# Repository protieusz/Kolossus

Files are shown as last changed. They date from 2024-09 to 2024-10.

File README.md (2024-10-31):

# Kolossus
Kolossus, a unisplit angled Katana layout with a 25mm trackball and a Panasonic roller encoder remixed from clops pcb designed by [calvin-mcd](https://github.com/calvin-mcd/clops). KLE by noelle (deer) and HA HA HA.

# PCBWay Sponsorship
The Kolossus PCB was sponsored by PCBWay. Thank you PCBWay! For all your PCB prototype prints and PCBA needs you can count on PCBWay. Easy and worry free service. You submit your gerber, BOM and placement files via their website. Enter the PCB dimensions and the quantity of the prints and select the recommend shipping service, for me it is the DHL Express (DTP) for hassle free delivery.  All customs paid for. PCBWay will email you component placement clear detailed pictures for validation before soldering the rest of the PCBs.

# Description
Kolossus "...is a qazlike unibody split sub40s keyboard. The KLE and firmware is by ha ha ha which itself is inspired by a KLE from Noelle. PCB is designed by Calvin0563." Copied from Calvin's GitHub linked above. 
Kolossus is a heavy remix of clops by adding a full case to the PCB that was made from scratch using EasyEDA by extracting vital files from the Calvin0563's clops PCB files. Initially the name was Colossus but changed to Kolossus via HA HA HA's suggestion to give it a more stylist name.
Here are the list of modifications:

-Center encoder is now a 25mm trackball powered by PMW3360 sensor.

-Full enclosure case with 4 RGB cut outs.

-5mm integrated switch plate to the top case.

-Use M2 brass hot inserts 3.2mm diameter and 4mm length for the M2 screws to secure the case. I forgot how long is my M2 screws are but they should be greater than 10mm so estimated around 14.6mm. Play around with and buy multiple M2 lenght screws.

-PCB is powered by [RP2040 Zero Super Mini](https://www.aliexpress.com/item/1005007292787135.html?spm=a2g0o.order_list.order_list_main.11.46301802CibF9u) where the bottom of the mcu is flush and can sit on top of the Excelsior PCB with no issues.

-For diodes, I decided to try out the BAV70 so that I solder less diodes. I would only need to solder on 17 diodes instead of 34

-QMK code is borrowed from aki27 bally and modified the matrix to fit my Kolossus. No suppport will be given since I just copy and paste.

-Below the trackball is the optional Panasonic EVQ roller encoder or a MX switch. Case cut out was done to acoomodate the Panasonic encoder.

-Stabilizers cutout was made but was not sure about the dimensions since I have never used stabs before so a STEP case file will be included so you can cut the stab cut out further if needed. I am planning to build mine without any stabs. As always print at your own risk. No support will be given.

-Case usb c opening ~~will be~~ adjusted ~~in the future~~ to accommodate the wider USB C magnetic port. Updated bottom case on October 31, 2024.

-New full case variant designs will be printed soon. Stay tuned.

-Full production build on Oct 22, 2024.

-For Encoder soldering, the MCU will need to be soldered a little bit to the left so that there is a little bit more space for the tiny GPIO pads to be exposed for surgical soldering. The pads are tiny so I suggest a ribbon cable type cables to be use. I have not solder build the pcb with roller encoder yet. I am currently still waiting for 2x RP2040 Super mini mcus to arrive from Aliexpress.

# Disclaimer (Also copied from Calvin0563's GitHub page)

Please note that this project is a work in progress with no guarantees of a working outcome. No-one involved in this project is responsible for any usage issues that may arise. However, feel free to edit, modify and otherwise utilise these files.

# Full Production Build
Zaku 2.0 case Oct 30, 2024











Zaku Case Oct 25, 2024


































# Render
Screenshot 2024-09-26 at 8 04 03 AM
Screenshot 2024-09-26 at 8 04 16 AM
Screenshot 2024-09-26 at 8 04 31 AM
Screenshot 2024-09-26 at 8 04 43 AM
Screenshot 2024-09-20 at 4 23 53 PM
Screenshot 2024-09-20 at 4 23 34 PM
Screenshot 2024-09-20 at 4 19 32 PM
Screenshot 2024-09-20 at 4 18 53 PM
Screenshot 2024-09-20 at 4 24 03 PM
Screenshot 2024-09-20 at 10 55 51 AM
Screenshot 2024-09-20 at 10 55 34 AM
Screenshot 2024-09-20 at 10 55 24 AM
Screenshot 2024-09-20 at 1 13 23 PM
Screenshot 2024-09-20 at 1 34 12 AM
Screenshot 2024-09-19 at 9 18 57 PM
Screenshot 2024-09-19 at 9 19 31 PM

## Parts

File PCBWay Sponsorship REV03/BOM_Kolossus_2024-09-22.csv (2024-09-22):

ID | Name | Designator | Footprint | Quantity | Manufacturer Part | Manufacturer | Supplier | Supplier Part | Price | link
1 | NO | ENCA,ENCB | PIN 1-PIN | 2
2 | Switch | K000,K001,K002,K003,K004,K006,K007,K008,K009,K010,K100,K101,K102,K103,K104,K106,K107,K108,K109,K110,K200,K201,K202,K203,K204,K206,K207,K208,K209,K210,K303,K305,K307 | CHERRY_MX_100_MILLMAX | 33
3 | MX_ALPS-2U-REVERSEDSTABILIZERS-NOLED | KK306,KK304 | MX_ALPS-2U-REVERSEDSTABILIZERS-NOLED | 2
4 | Roll Encoder - EVQWGD001 | EC305 | EVQWGD001 ENCODER | 1 | EVQWGD001 | Panasonic | Aliexpress | EVQWGD001
5 | BAV70-C68978 | D007,D107,D207,D209,D306,D305,D000,D002,D004,D008,D100,D102,D104,D108,D200,D202,D204,D303 | SOT-23-3_L3.0-W1.7-P0.95-LS2.9-BR | 18 | BAV70 | CJ(江苏长电/长晶) | LCSC | C68978 | 0.019 | https://item.szlcsc.com/139341.html
6 | 4.7uF | C17,C19,C20 | C0402 | 3 | CL05A475MP5NRNC | SAMSUNG(三星) | LCSC | C23733 | 0.005 | https://lcsc.com/eda_search?q=C23733&%26type=1&ref=editor
7 | 100nF | C18 | C0402 | 1 | CL05B104KB54PNC | SAMSUNG(三星) | LCSC | C307331 | 0.005 | https://lcsc.com/eda_search?q=C307331&%26type=1&ref=editor
8 | 10kΩ | R10,R12,R13 | R0402 | 3 | 0402WGF1002TCE | UNI-ROYAL(厚声) | LCSC | C25744 | 0.001 | https://lcsc.com/eda_search?q=C25744&%26type=1&ref=editor
9 | 39Ω | R11 | R0402 | 1 | 0402WGJ0390TCE | UNI-ROYAL(厚声) | LCSC | C25164 |  | https://lcsc.com/eda_search?q=C25164&%26type=1&ref=editor
10 | 15kΩ | R14 | R0402 | 1 | 0402WGF1502TCE | UNI-ROYAL(厚声) | LCSC | C25756 | 0.001 | https://lcsc.com/eda_search?q=C25756&%26type=1&ref=editor
11 | AP2127K-ADJTRG1 | U10 | SOT-23-5_L3.0-W1.7-P0.95-LS2.8-BR | 1 | AP2127K-ADJTRG1 | DIODES(美台) | LCSC | C96343 | 0.074 | https://lcsc.com/eda_search?q=C96343&%26type=1&ref=editor
12 | PMW3360DM-T2QU | U11 | PMW3360DM-T2QU.PACK | 1 | PMW3360DM-T2QU |  |  |  |  | http://www.pixart.com/upload/PMS0058-PMW3360DM-T2QU-NNDS-R1.30-06042016_20160902201411.pdf
13 | RP2040-TINY | U2 | COMM-SMD_23P-P2.54-L23.5-W18.0_RP2040-TINY | 1 | RP2040-Tiny | Waveshare(微雪电子) | LCSC | C7437606 | 5.586 | https://atta.szlcsc.com/upload/public/pdf/source/20230712/B68EE20814230DC1A1AC8A477766A0F3.pdf
14 | SN74LVC1T45DCKR | U6L | SC-70-6_L2.2-W1.3-P0.65-LS2.2-BR | 1 | SN74LVC1T45DCKR | TI(德州仪器) | LCSC | C9382 | 0.118 | https://item.szlcsc.com/51804.html
15 | SK6812MINI-E_C5149201 | U20,U21,U22,U23 | LED-SMD_L3.2-W2.8-TR | 4 | SK6812MINI-E | 欧思科光电 | LCSC | C5149201 | 0.092 | https://lcsc.com/eda_search?q=C5149201&%26type=1&ref=editor

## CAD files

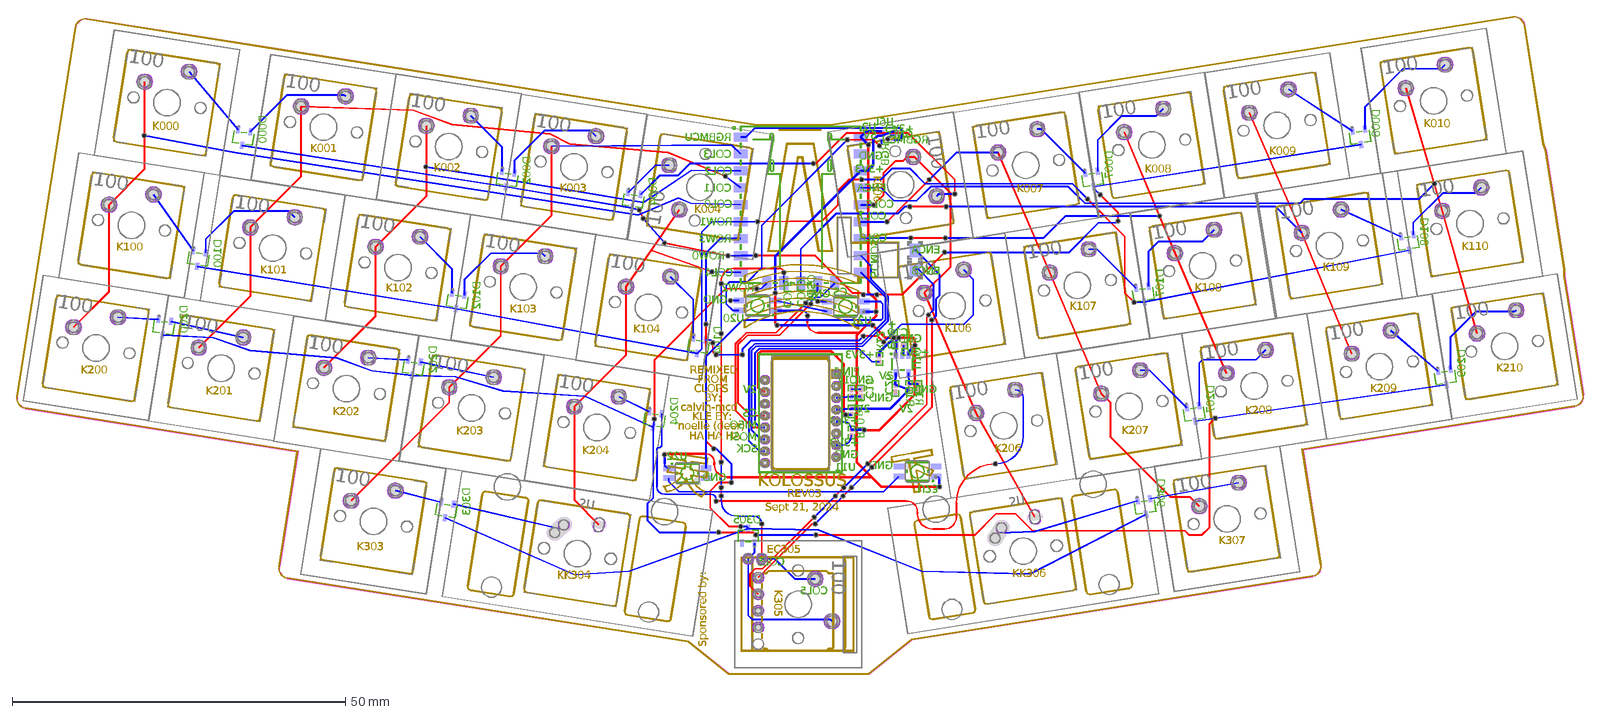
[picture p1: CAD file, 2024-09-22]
Final PCB Reference Corrected Sensor/PCB_Kolossus-Corrected-Sensor_2024-09-22.dxf
KOLOSSUS
REV03
Sept 21, 2024
REMIXED
FROM
CLOPS
BY:
calvin-mcd
KLE BY:
noelle (deer)
HA HA HA
Sponsored by:
PIN 1
GND
2V
+3V3
CS
MISO
MOSI
SCK
COL5
5V
RGBMCU
RGB
ENCA
COL6
COL7
COL8
COL9
COL4
ROW0
ROW3
ROW1
COL0
COL1
COL2
COL3
ROW2
K305
100
KK306
2U
KK304
K006
K007
K008
K009
K010
K106
K107
K108
K109
K110
K206
K207
K208
K209
K210
K307
EC305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

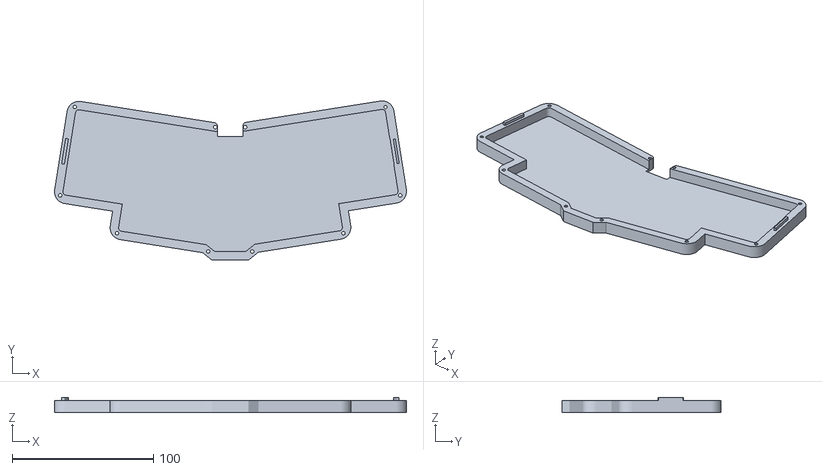
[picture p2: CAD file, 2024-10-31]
STLs/Kolossus Bottom WiderUSB.stl
249.1 x 112.6 x 10.6

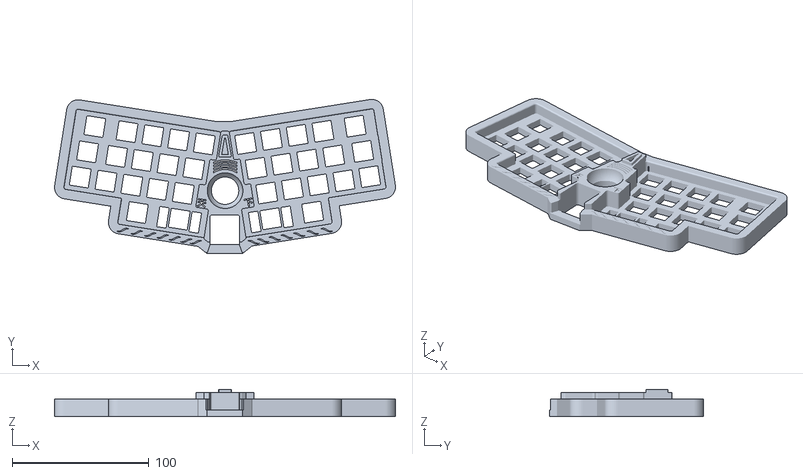
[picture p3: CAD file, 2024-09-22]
STLs/Kolossu Top Case.stl
249.1 x 112.6 x 20.0

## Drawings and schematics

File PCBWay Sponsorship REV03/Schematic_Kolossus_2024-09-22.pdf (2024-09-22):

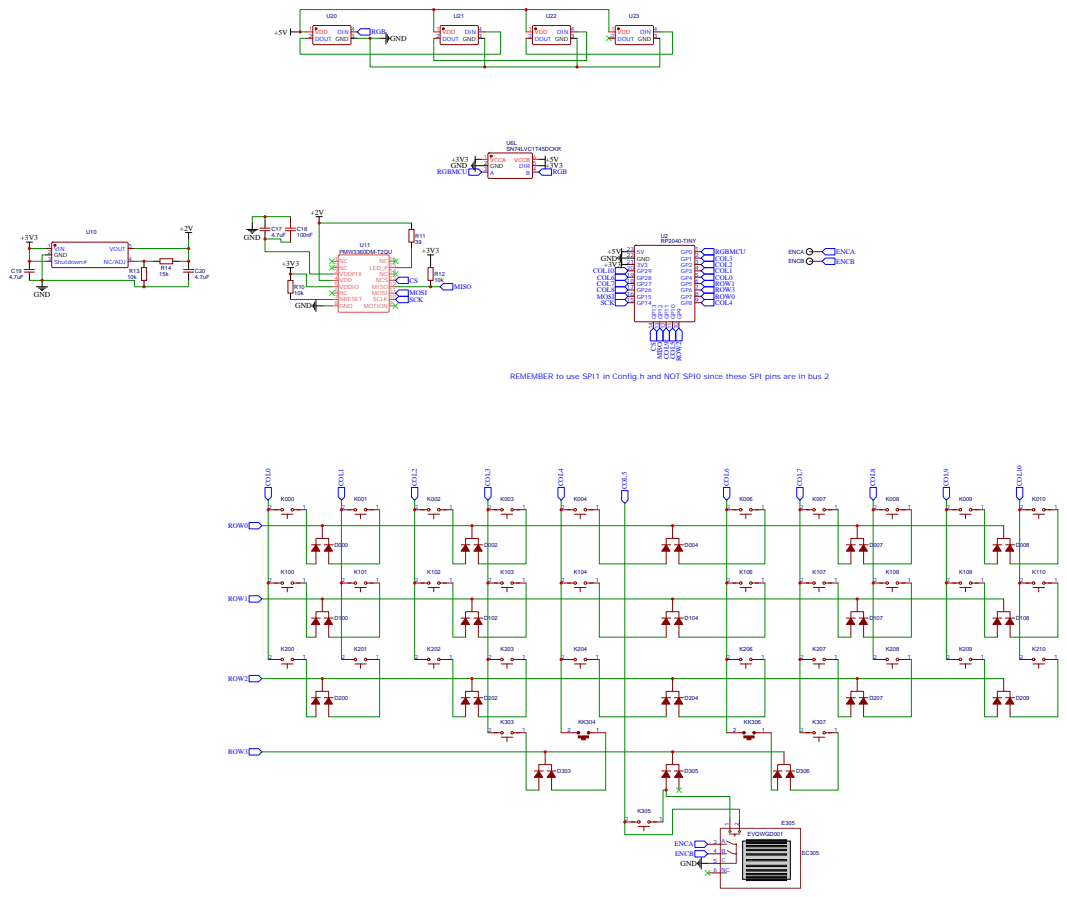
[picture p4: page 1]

REMEMBER to use SPI1 in Config.h and NOT SPI0 since these SPI pins are in bus 2

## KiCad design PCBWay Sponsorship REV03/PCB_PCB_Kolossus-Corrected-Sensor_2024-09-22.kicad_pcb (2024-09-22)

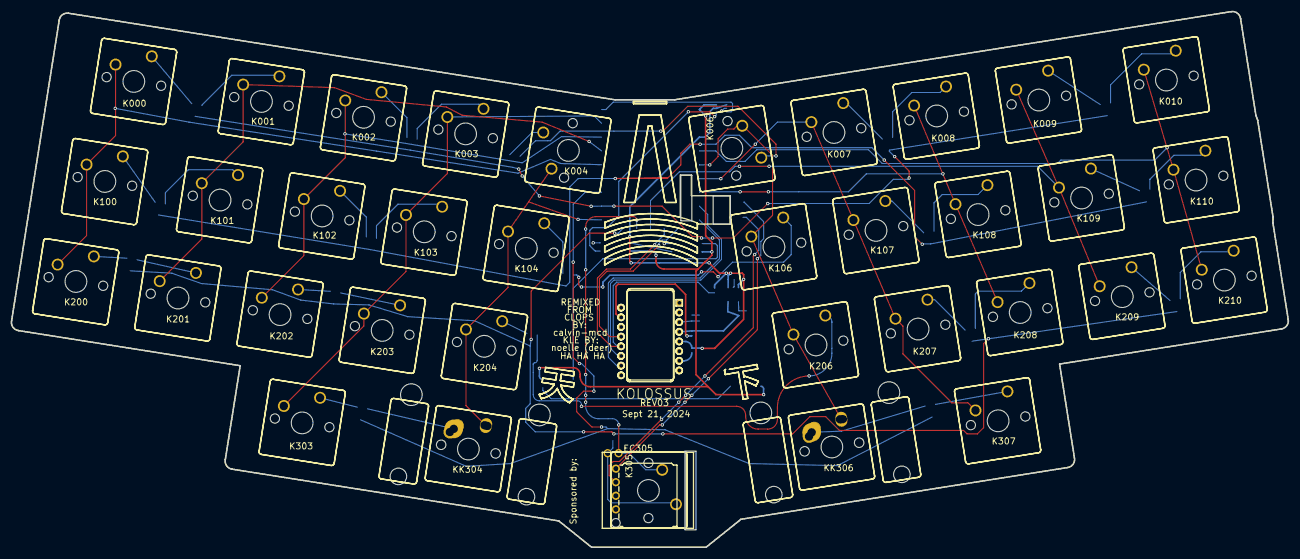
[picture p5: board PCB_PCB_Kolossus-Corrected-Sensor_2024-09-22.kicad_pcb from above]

Board: 2 copper layers, 235.1 x 98.6 mm, 73 parts (0 on the bottom side), 69 nets.

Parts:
C17, C19, C20: 4.7uF; C0402
C18: 100nF; C0402
D000, D002, D004, D007, D008, D100, D102, D104, D107, D108, D200, D202, D204, D207, D209, D303, D305, D306: BAV70-C68978; SOT-23-3_L3.0-W1.7-P0.95-LS2.9-BR
EC305: Roll Encoder - EVQWGD001; EVQWGD001 ENCODER
ENCA: NO; PIN 1-PIN
ENCB: NO; PIN 1-PIN
K000, K001, K002, K003, K004, K006, K007, K008, K009, K010, K100, K101, K102, K103, K104, K106, K107, K108, K109, K110, K200, K201, K202, K203, K204, K206, K207, K208, K209, K210, K303, K305, K307: 100; CHERRY_MX_100_MILLMAX
KK304, KK306: 2U; MX_ALPS-2U-REVERSEDSTABILIZERS-NOLED
R10, R12, R13: 10kΩ; R0402
R11: 39Ω; R0402
R14: 15kΩ; R0402
U2: RP2040-TINY; COMM-SMD_23P-P2.54-L23.5-W18.0_RP2040-TINY
U6L: SN74LVC1T45DCKR; SC-70-6_L2.2-W1.3-P0.65-LS2.2-BR
U10: AP2127K-ADJTRG1; SOT-23-5_L3.0-W1.7-P0.95-LS2.8-BR
U11: PMW3360DM-T2QU; PMW3360DM-T2QU.PACK
U20, U21, U22, U23: SK6812MINI-E_C5149201; LED-SMD_L3.2-W2.8-TR

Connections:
+2V: C20.2, R11.2, R14.2, U10.5, U11.4
+3V3: C19.2, R10.2, R12.2, U2.21, U6L.1, U6L.5, U10.1, U10.3, U11.5
+5V: U2.23, U6L.6, U20.1, U21.1, U22.1, U23.1
COL0: K000.2, K100.2, K200.2, U2.5
COL1: K001.2, K101.2, K201.2, U2.4
COL2: K002.2, K102.2, K202.2, U2.3
COL3: K003.2, K103.2, K203.2, K303.2, U2.2
COL4: K004.2, K104.2, K204.2, KK304.2, U2.9
COL5: EC305.2, K305.2, U2.11
COL6: K006.2, K106.2, K206.2, KK306.2, U2.19
COL7: K007.2, K107.2, K207.2, K307.2, U2.18
COL8: K008.2, K108.2, K208.2, U2.17
COL9: K009.2, K109.2, K209.2, U2.12
COL10: K010.2, K110.2, K210.2, U2.20
CS: U2.14, U11.13
D303_2: D303.2, KK304.1
D306_1: D306.1, KK306.1
EC305_1: D305.1, EC305.1, K305.1
ENCA: EC305.3, ENCA.1
ENCB: EC305.4, ENCB.1
GND: C17.2, C18.2, C19.1, C20.1, EC305.5, R13.1, U2.22, U6L.2, U10.2, U11.8, U20.3, U21.3, U22.3, U23.3
K000_1: D000.1, K000.1
K001_1: D000.2, K001.1
K002_1: D002.1, K002.1
K003_1: D002.2, K003.1
K004_1: D004.1, K004.1
K006_1: D004.2, K006.1
K007_1: D007.1, K007.1
K008_1: D007.2, K008.1
K009_1: D008.1, K009.1
K010_1: D008.2, K010.1
K100_1: D100.1, K100.1
K101_1: D100.2, K101.1
K102_1: D102.1, K102.1
K103_1: D102.2, K103.1
K104_1: D104.1, K104.1
K106_1: D104.2, K106.1
K107_1: D107.1, K107.1
K108_1: D107.2, K108.1
K109_1: D108.1, K109.1
K110_1: D108.2, K110.1
K200_1: D200.1, K200.1
K201_1: D200.2, K201.1
K202_1: D202.1, K202.1
K203_1: D202.2, K203.1
K204_1: D204.1, K204.1
K206_1: D204.2, K206.1
K207_1: D207.1, K207.1
K208_1: D207.2, K208.1
K209_1: D209.1, K209.1
K210_1: D209.2, K210.1
K303_1: D303.1, K303.1
K307_1: D306.2, K307.1
MISO: R12.1, U2.13, U11.12
MOSI: U2.16, U11.11
RGB: U6L.4, U20.4
RGBMCU: U2.1, U6L.3
ROW0: D000.3, D002.3, D004.3, D007.3, D008.3, U2.8
ROW1: D100.3, D102.3, D104.3, D107.3, D108.3, U2.6
ROW2: D200.3, D202.3, D204.3, D207.3, D209.3, U2.10
ROW3: D303.3, D305.3, D306.3, U2.7
SCK: U2.15, U11.10
U10_4: R13.2, R14.1, U10.4
U11_3: C17.1, C18.1, U11.3
U11_7: R10.1, U11.7
U11_15: R11.1, U11.15
U20_2: U20.2, U21.4
U21_2: U21.2, U22.4
U23_4: U22.2, U23.4

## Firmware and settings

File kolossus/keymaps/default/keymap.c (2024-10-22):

/* Copyright 2024 ProtieusKeebs
 * 
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
 * You should have received a copy of the GNU General Public License
 * along with this program.  If not, see <http://www.gnu.org/licenses/>.
 */
#include QMK_KEYBOARD_H

enum combo_events {
  COMBO_DEL,
  COMBO_ESC,
  COMBO_CTRL,
  COMBO_ALT,
  COMBO_LENGTH
};
uint16_t COMBO_LEN = COMBO_LENGTH;

const uint16_t PROGMEM combo_del[] = {KC_Y, KC_H, COMBO_END};
const uint16_t PROGMEM combo_esc[] = {KC_T, KC_G, COMBO_END};
const uint16_t PROGMEM combo_ctrl[] = {KC_Q, KC_W, COMBO_END};
const uint16_t PROGMEM combo_alt[] = {KC_O, KC_P, COMBO_END};

combo_t key_combos[] = {
  [COMBO_DEL] = COMBO(combo_del, KC_DEL),
  [COMBO_ESC] = COMBO(combo_esc, KC_ESC),
  [COMBO_CTRL] = COMBO(combo_ctrl, KC_LCTL),
  [COMBO_ALT] = COMBO(combo_alt, KC_RALT),
};

layer_state_t layer_state_set_user(layer_state_t state) {
    return update_tri_layer_state(state, 1, 2, 3);
} 

const uint16_t PROGMEM keymaps[][MATRIX_ROWS][MATRIX_COLS] = {
    
    [0] = LAYOUT(
        KC_Q,         KC_W, KC_E,    KC_R,    KC_T,                          KC_Y,          KC_U,          KC_I,     KC_O,   KC_P,
        KC_A,         KC_S, KC_D,    KC_F,    KC_G,                          KC_H,          KC_J,          KC_K,     KC_L,   KC_SCLN,
        LSFT_T(KC_Z), KC_X, KC_C,    KC_V,    KC_B,                          KC_N,          KC_M,          KC_COMMA, KC_DOT, RSFT_T(KC_SLSH),
                                     KC_LGUI, LT(1,KC_BSPC),    SCRL_MO,     LT(2,KC_SPC),  (KC_ENT)                               
    ),
    [1] = LAYOUT(
        KC_1,    KC_2,    KC_3,    KC_4,          KC_5,                                      KC_6,     KC_7,    KC_8,    KC_9,    KC_0,
        KC_TAB,  SCRL_MO, KC_MS_BTN2, KC_MS_BTN1, _______,                                   KC_MINS,  KC_EQL,  KC_LBRC, KC_RBRC, KC_QUOT,
        _______, _______, KC_MUTE, KC_VOLD,       KC_VOLU,                                   KC_TILD,  KC_GRV,  _______, _______, KC_BSLS,
                                   _______,       _______,             _______,              _______,  _______                  
    ),
    [2] = LAYOUT(
        KC_EXLM, KC_AT,   KC_HASH, KC_DLR,  KC_PERC,                                     KC_CIRC, KC_AMPR, KC_ASTR, KC_LPRN, KC_RPRN,
        RGB_VAI, RGB_SAI, RGB_HUI, RGB_SPI, RGB_MOD,                                     RGB_TOG,  _______, _______, _______, _______, 
        RGB_VAD, RGB_SAD, RGB_HUD, RGB_SPD, RGB_RMOD,                                    _______,  _______, _______, _______, _______,
                                    _______, _______,            _______,                _______,  _______

    ),
    [3] = LAYOUT(
        _______, KC_UP, _______, _______, _______,                                           KC_F1,   KC_F2,   KC_F3,   KC_F4,   KC_PSCR,
        KC_LEFT, KC_DOWN, KC_RIGHT, _______, _______,                                        KC_F5,   KC_F6,   KC_F7,   KC_F8,   KC_F9,
        _______, _______, ROT_L15, ROT_R15, CPI_SW,                                          KC_F10,  KC_F11,  KC_F12,  _______, _______,
                                   _______,  _______,            _______,                    _______, _______
    )
};

#if defined(ENCODER_MAP_ENABLE)
const uint16_t PROGMEM encoder_map[][NUM_ENCODERS][2] = {
    [0] =  { ENCODER_CCW_CW(KC_MS_WH_UP, KC_MS_WH_DOWN)  },
    [1] =  { ENCODER_CCW_CW(KC_MS_WH_LEFT, KC_MS_WH_RIGHT) },
    [2] =  { ENCODER_CCW_CW(KC_PGUP, KC_PGDN)  },
    [3] =  { ENCODER_CCW_CW(KC_VOLD, KC_VOLU)  } 
    //[4] =  { ENCODER_CCW_CW(XXXXXXX, XXXXXXX) }
};
#endif

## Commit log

2024-09-22 Untested Production Files
    [BOM_Kolossus_2024-09-22.csv, PCB_PCB_Kolossus-Corrected-Sensor_2024-09-22.kicad_pcb, PickAndPlace_PCB_Kolossus-Corrected-Sensor_2024-09-22.csv]
2024-09-22 STLs & 3mf
    [Kolossu Bottom.stl, Kolossu Top Case.stl, UMS7_Kolossu Top Bottom Case.3mf]
2024-09-22 PCB DXF
    [PCB_Kolossus-Corrected-Sensor_2024-09-22.dxf]
2024-10-31 Wider USB C for magnetic plug.
    [Kolossus Bottom WiderUSB.stl]

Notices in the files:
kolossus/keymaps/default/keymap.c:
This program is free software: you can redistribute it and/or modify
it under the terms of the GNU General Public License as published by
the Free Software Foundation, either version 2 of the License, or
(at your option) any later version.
